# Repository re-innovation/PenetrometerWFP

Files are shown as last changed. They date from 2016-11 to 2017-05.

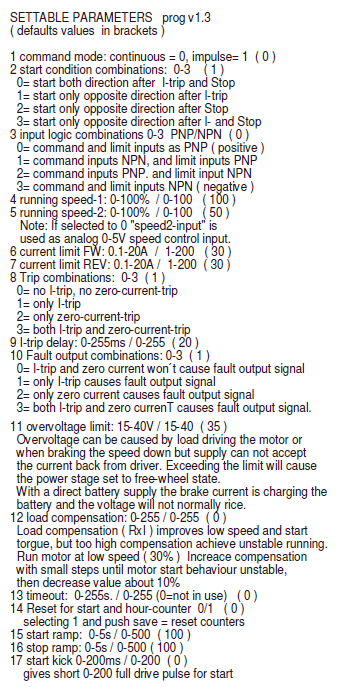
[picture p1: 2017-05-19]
Datasheets/motorcontrol.png

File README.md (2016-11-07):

# PenetrometerWFP
Penetrometer for measuing sludge. Produced for Water For People and Mott MacDonald.
This repository is for the electrical system wiring and control program.
Updates and improvements can be made to this code and kept track of.

# Hardware
See datasheets for hardware specifications.

See diagrams form hardware connection diagrams.

# Software
The control program has been written using DAQFactory Express.
This is the free to download version of the software.
Available here:
http://www.azeotech.com/j/downloads.html

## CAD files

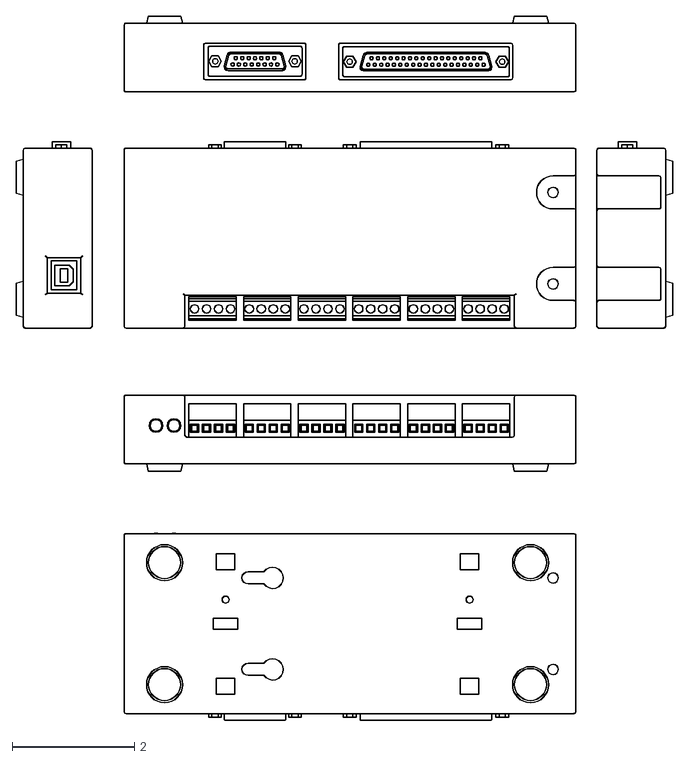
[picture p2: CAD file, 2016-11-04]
Datasheets/U6_sizes.DXF
10.8 x 11.5

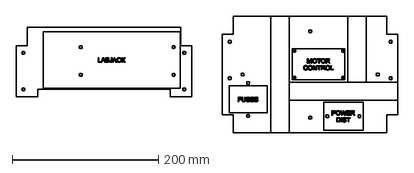
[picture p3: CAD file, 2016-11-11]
Diagrams/2016_11_07_Penetrometer_Electrical_System_Baseplate_3mm_Acrylic.dxf
522.4 x 160.0 mm

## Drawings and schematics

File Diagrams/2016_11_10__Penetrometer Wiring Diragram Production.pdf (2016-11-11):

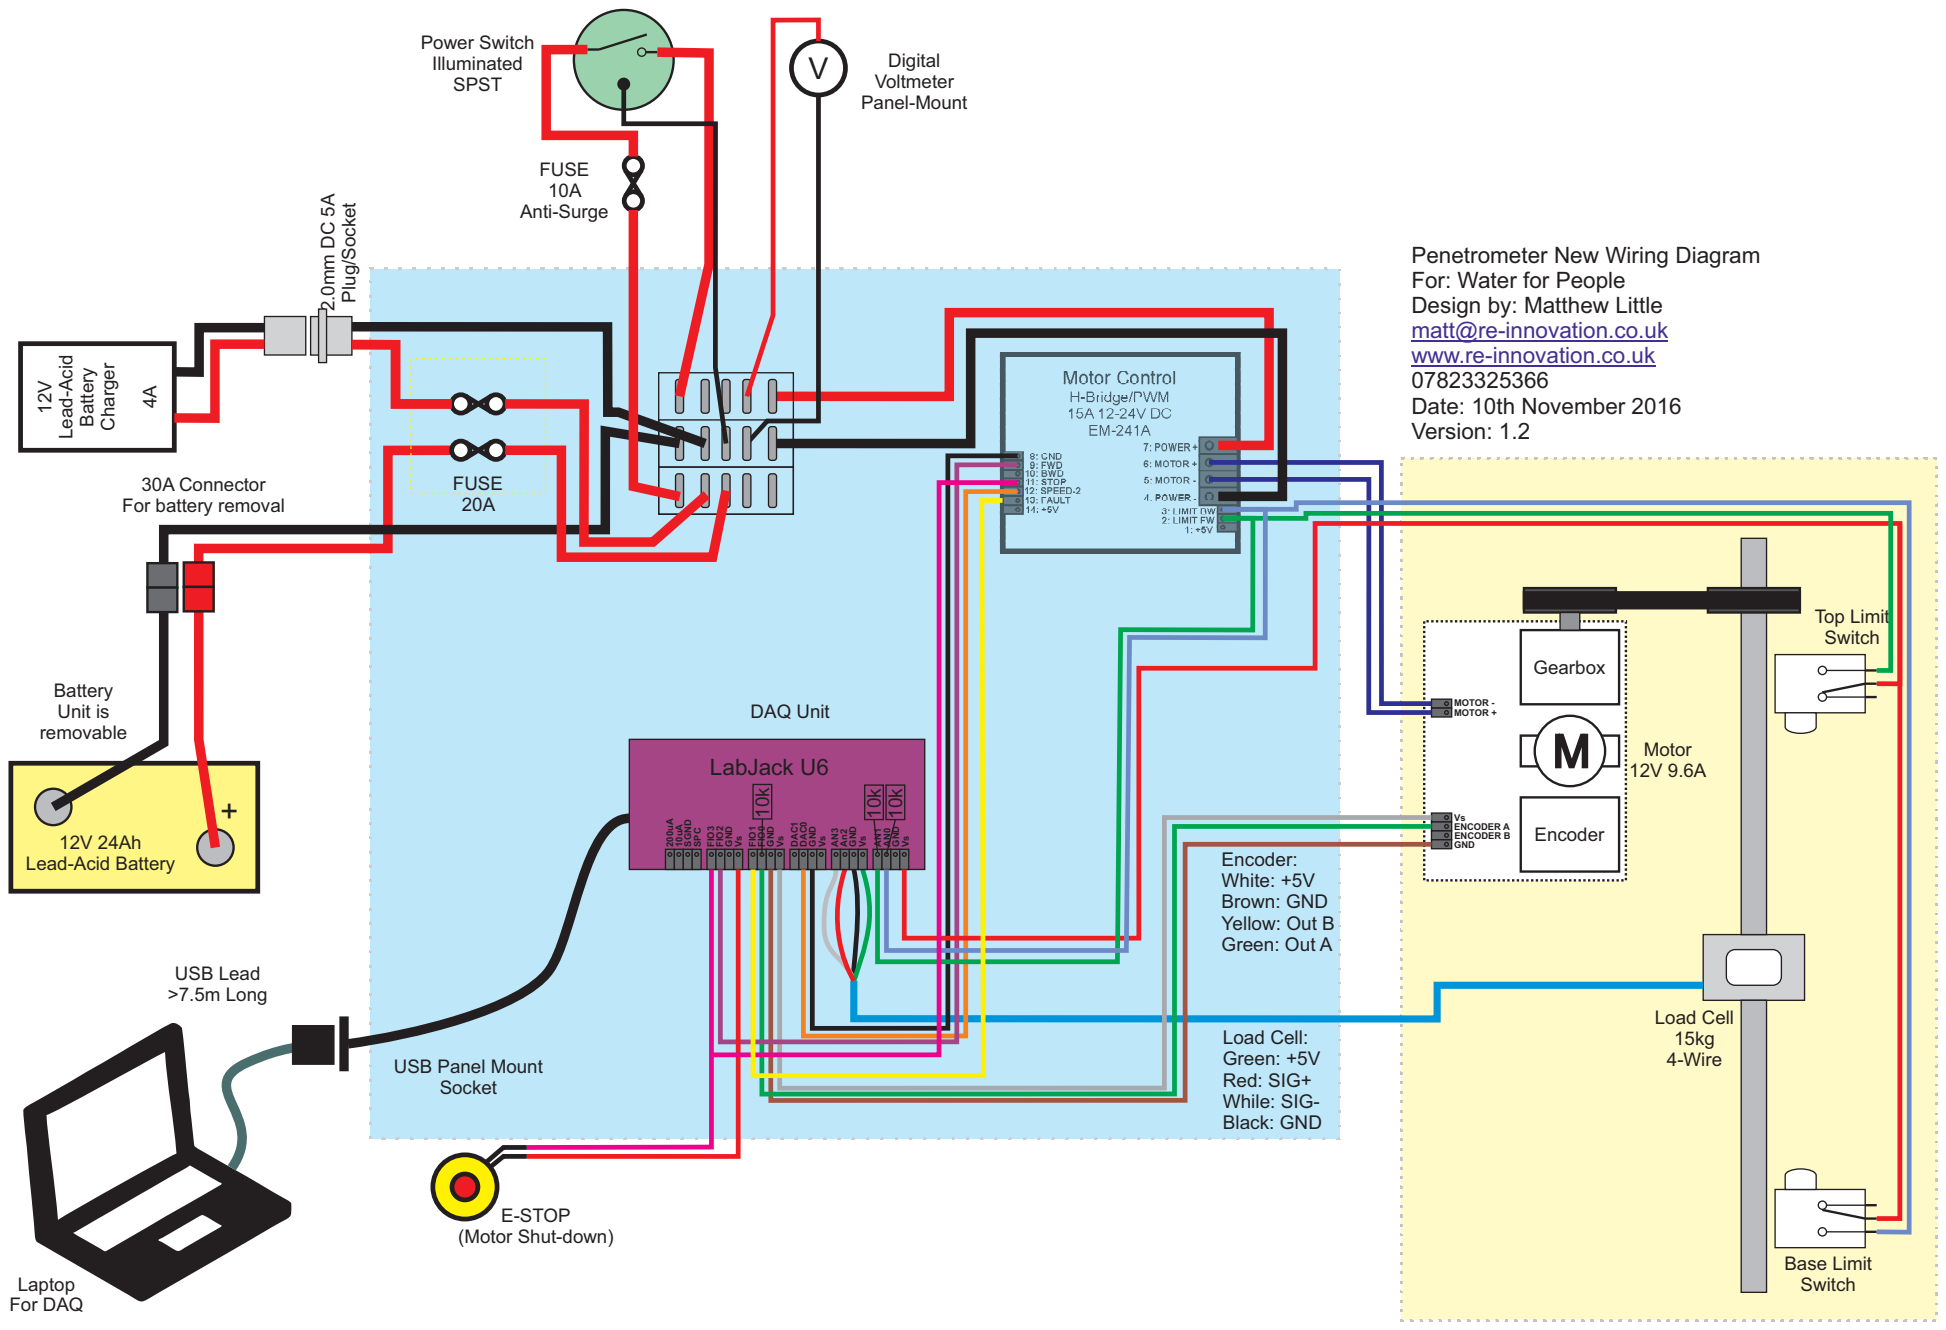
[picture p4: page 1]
Motor Control H-Bridge/PWM 15A 12-24V DC EM-241A; 5: MOTOR -; 6: MOTOR +; 12: SPEED-2; 9: FWD; 3: LIMIT BW 2: LIMIT FW 1: +5V; 4: POWER -; 7: POWER +; 11: STOP; 8: GND; 10: BWD; 13: FAULT; Lead-Acid; Battery; Charger; Base Limit Switch; Top Limit Switch; FUSE 10A Anti-Surge; Plug/Socket; Motor 12V 9.6A; Load Cell 15kg 4-Wire; DAQ Unit; USB Lead >7.5m Long; Laptop For DAQ; Power Switch Illuminated; SPST; Digital Voltmeter; Panel-Mount; Gearbox; Encoder; LabJack U6; SGND; SPC; FIO3; FIO2; GND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

Penetrometer New Wiring Diagram
For: Water for People
Design by: Matthew Little
matt@re-innovation.co.uk
www.re-innovation.co.uk
Date: 10th November 2016
Version: 1.2

30A Connector
For battery removal

Lead-Acid Battery

USB Panel Mount
Socket

E-STOP
(Motor Shut-down)

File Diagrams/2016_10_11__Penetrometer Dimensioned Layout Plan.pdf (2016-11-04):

# BACK OF UNIT

# EXTENSION ROD

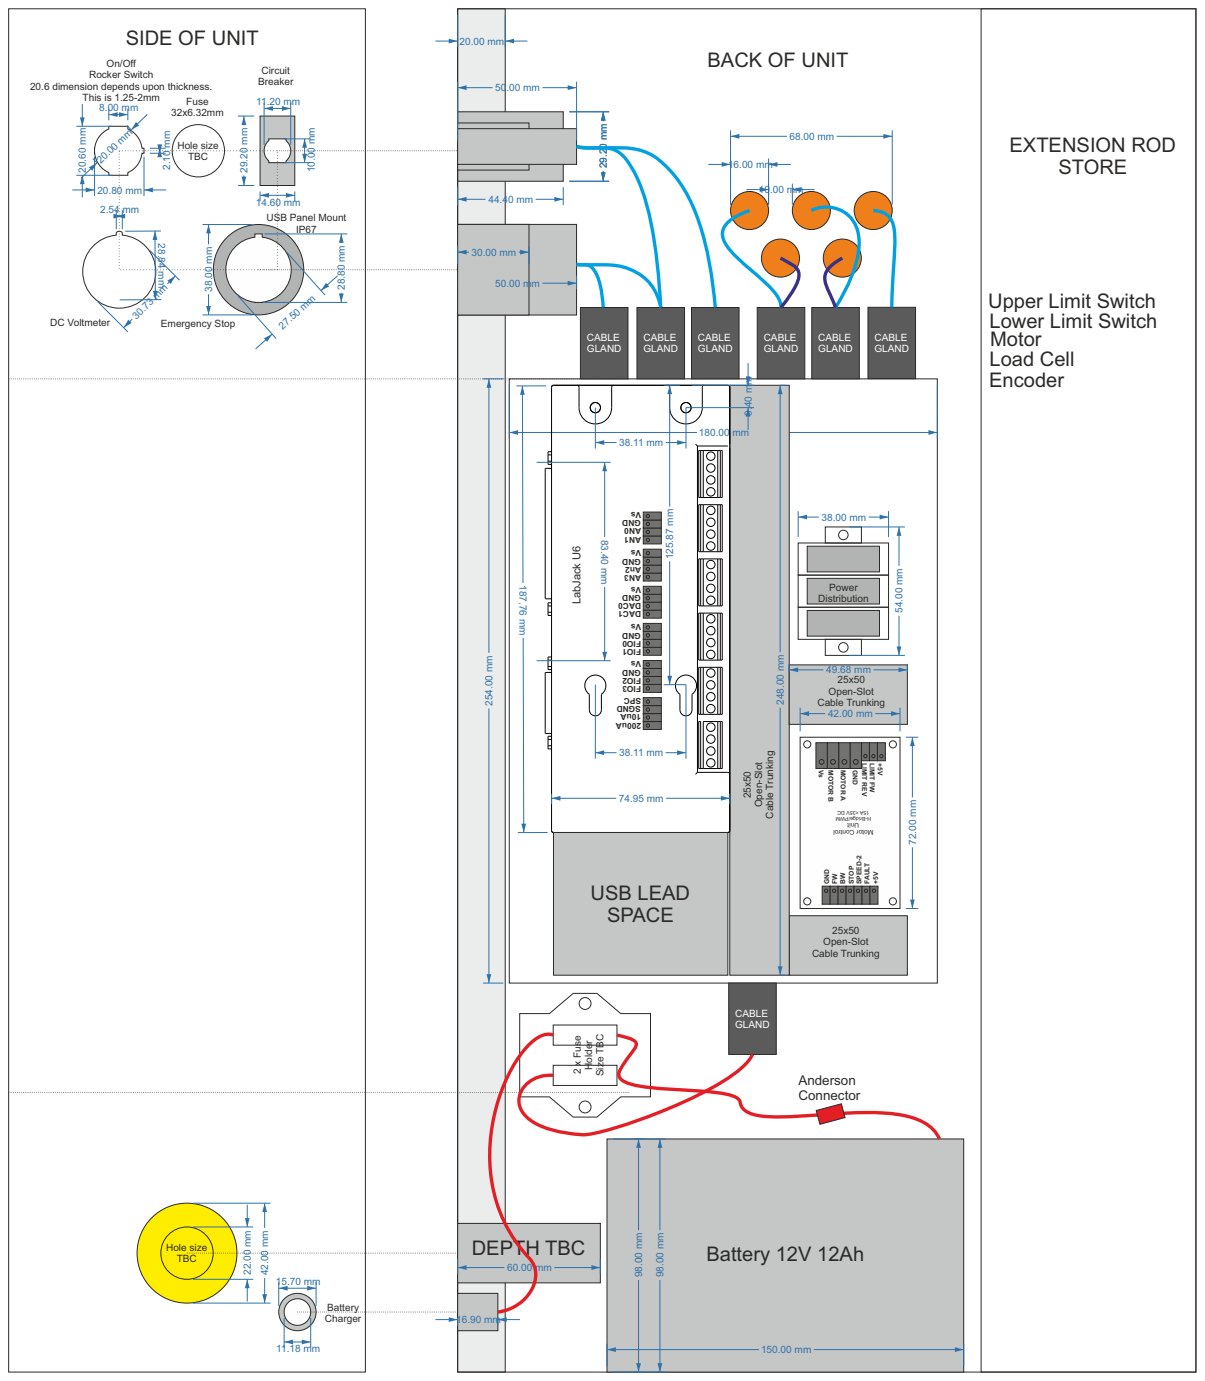
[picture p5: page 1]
FAULT; SPEED-2; GND; LIMIT REV; LIMIT FW; MOTOR B; MOTOR; LabJack U6; USB LEAD SPACE; Hole size TBC; Emergency Stop; Fuse 32x6.32mm; On/Off Rocker Switch; This is 1.25-2mm; Circuit Breaker; DC Voltmeter; 25x50 Open-Slot Cable Trunking; Open-Slot; Cable; Trunking; Power Distribution; Battery 12V 12Ah; 2 x Fuse; Holder; Size TBC; Battery Charger; STORE; DEPTH TBC; CABLE GLAND; Anderson Connector

SIDE OF UNIT

20.6 dimension depends upon thickness.

USB Panel Mount

Upper Limit Switch
Lower Limit Switch
Motor
Load Cell
Encoder

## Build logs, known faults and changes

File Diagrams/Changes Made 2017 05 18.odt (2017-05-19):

Changes made to reverse the motor direction (due to gear changing direction):

1. On Motor controller: Swap motor power wires
2. Update motor control set points
3. On Motor controller: Swap limit switch lines (Conenctors 2 and 3 swapped around)
4. Added extensions for limit switches to ensure good point of contact

Changes made to software:

1. Altered distance calc
2. Altered Up/Down limits check
3. Altered Rod remove algorithm
4. Changed leadscrew value
5. Added UNITID/IND/DISTRICT/LONG/LAT for file name
6. Changed ramp up/down settings to make motor stop quicker and put less stress on limit switches.
7. "Cancel" on pop ups should now work!
8. Added user input for UNITID, IND,DIST, LONGITUDE,LATITUDE at start up. Just warning to enter when started. Will not run test without detail entered.

Changes still needed:

1. Level action micro switches as limit stops are too 'hard'
2. Need Leadscrew mm per rotation movement. Assumption is that its 10.0mm/rev.
3. Calibrate load cell
4. Calibrate distance measurement

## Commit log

2016-11-04 Initial commit
    Commit of initial program
    [U6_sizes.DXF]
2016-11-04 Updated control program
    Sorted Display
    Sorted Distance sensor
    Sorted Test control algorithm
    TO DO: Ensure data is saved correctly
2016-11-07 Sorted DAC speed output
    Needed motor controller to do this
2016-11-07 Added baseplate .dxf
    [2016_11_07_Penetrometer_Electrical_System_Baseplate_3mm_Acrylic.dxf]
2016-11-11 Update of all files
    Works with production wiring
    [2016_11_07_Penetrometer_Electrical_System_Baseplate_3mm_Acrylic.dxf]
